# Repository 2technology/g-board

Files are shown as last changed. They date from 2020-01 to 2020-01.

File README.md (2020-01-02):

# G-board V 0.1!
PCB design in order to use a ESP32 DevkitC to drive a relay and 4 seperate WS2812b-channels. It has terminal blocks for easy installation and up to 4 pushbuttons can be connected. It uses a Logic level shifter to communicate with the WS2812b led drivers. **Use case:** Smart lights room controller for Home assistant (ESP32 firmware created with ESPHome).

  - [ESP32 DEVKIT C 32D](https://www.aliexpress.com/item/4000434690235.html)
  - 4 * I2C connection headers
  - 1 * 12V Relay rated 16A ([Schrack RTD34012](https://www.tme.eu/en/details/rtd34012/miniature-electromagnetic-relays/te-connectivity/3-1419108-5/) )
  - 4 * WS2812b LED Output channels (with Logic Level Shifter [74HCT245N](https://www.aliexpress.com/item/4000115614415.html))
  - 4 * debounced pushbutton inputs
  
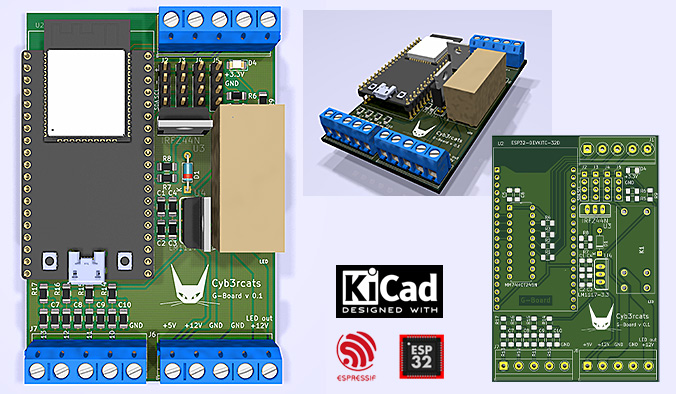
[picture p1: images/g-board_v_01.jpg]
G-Board Version 0.1 G-Board V0.1

  
### Features
#### 12V Relay rated 16A ([Schrack RTD34012](https://www.tme.eu/en/details/rtd34012/miniature-electromagnetic-relays/te-connectivity/3-1419108-5/) )
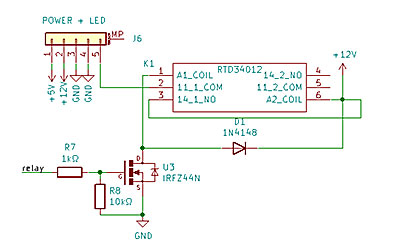
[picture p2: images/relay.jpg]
Relay

#### 4 debounced pushbutton inputs
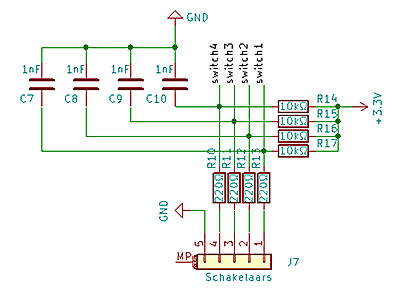
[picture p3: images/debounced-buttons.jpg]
Input-buttons debounced inputs


#### 4 WS2812b LED Output channels (with Logic Level Shifter [74HCT245N](https://www.aliexpress.com/item/4000115614415.html))
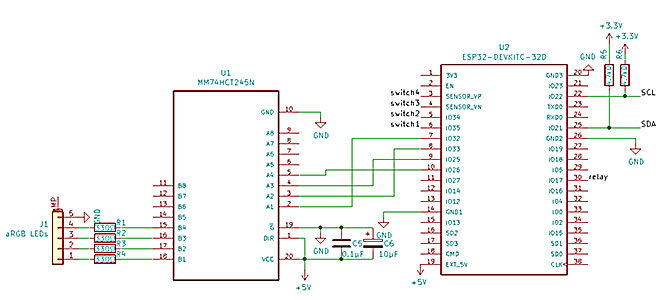
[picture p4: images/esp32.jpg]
Logic-level-shifting esp32


### Schematic and PCB
View [Schematic (pdf)](https://github.com/2technology/g-board/blob/master/G-Board%20V0.1%20-%20Schematic.pdf)

Download KiCAD files: [Schematic](https://github.com/2technology/g-board/blob/master/G-board_V0_1.sch), [PCB](https://github.com/2technology/g-board/blob/master/G-board_V0_1.kicad_pcb)

### Gerbers
Download [Gerbers](https://github.com/2technology/g-board/blob/master/gerbers.zip)
### BOM

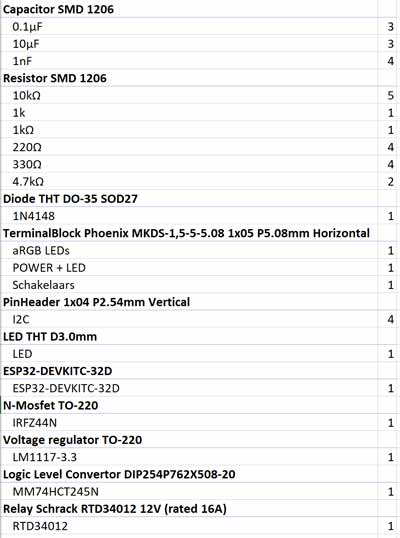
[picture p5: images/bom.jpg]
BOM Version 0.1 BOM G-Board V0.1


### Licence
[GPL-3.0](https://github.com/2technology/g-board/blob/master/LICENSE)

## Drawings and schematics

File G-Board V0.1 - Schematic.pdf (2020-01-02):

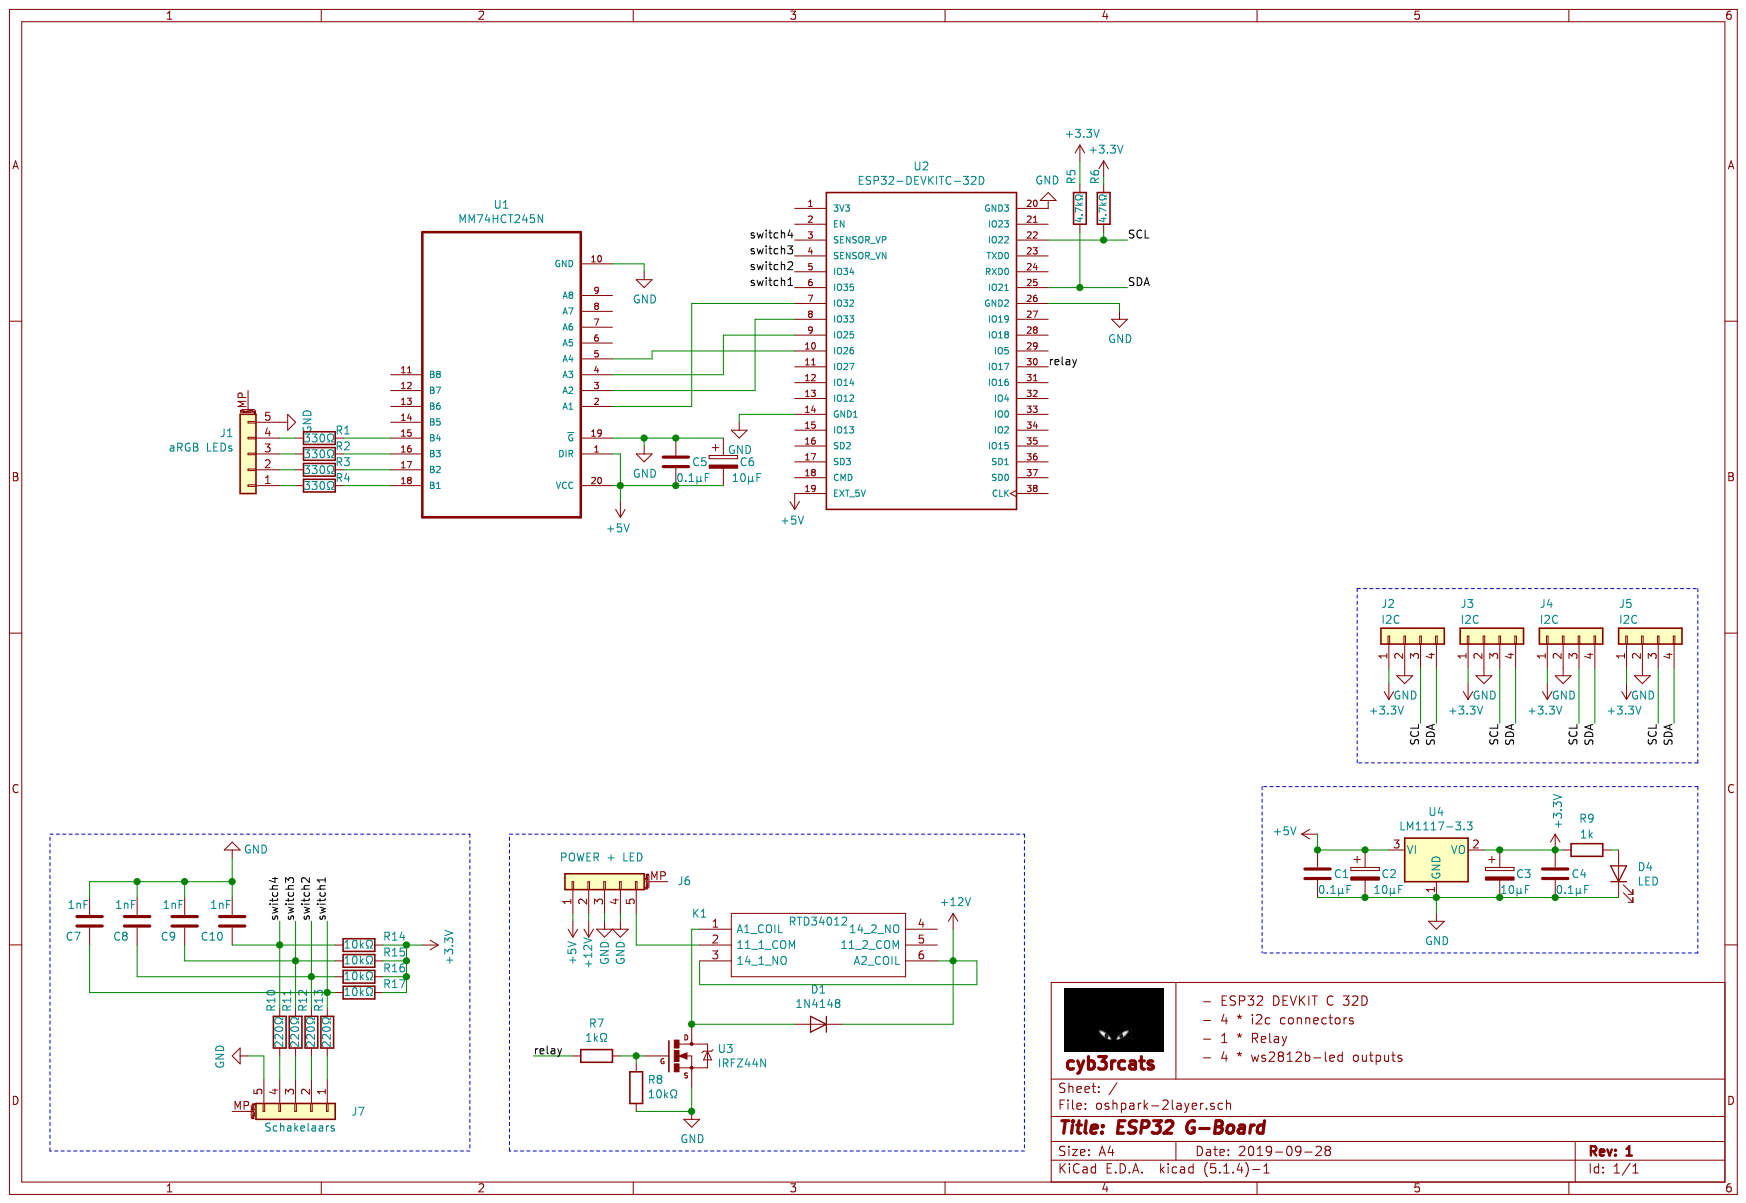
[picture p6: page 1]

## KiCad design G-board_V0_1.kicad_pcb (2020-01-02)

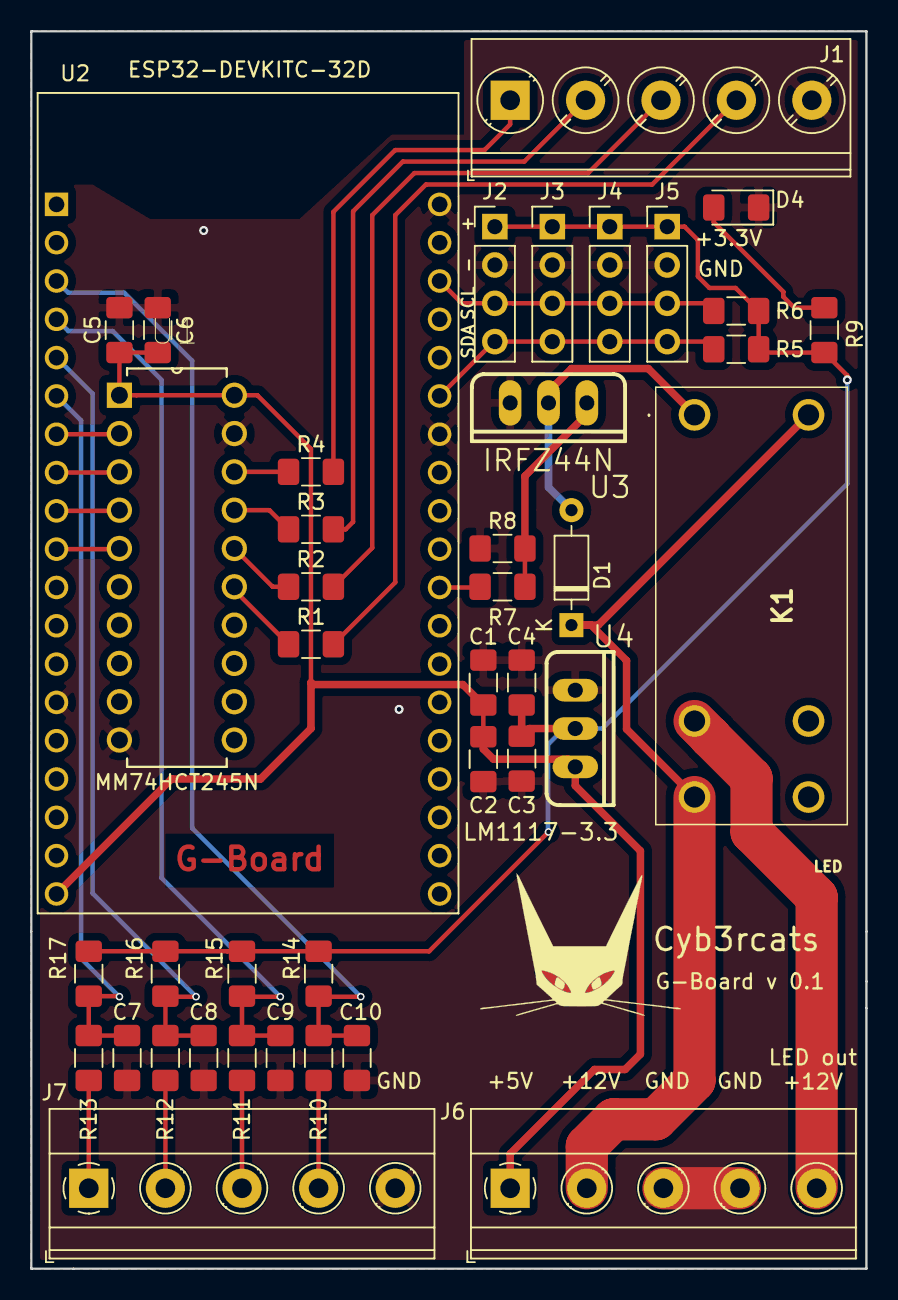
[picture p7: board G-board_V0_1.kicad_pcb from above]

Board: 2 copper layers, 55.4 x 82.0 mm, 42 parts (0 on the bottom side), 31 nets.

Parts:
*: Cyb3rcats; cybercats_logo_silk_cu
C1, C4, C5: 0.1μF; R_1206_3216Metric_Pad1.42x1.75mm_HandSolder
C2, C3, C6: 10μF; R_1206_3216Metric_Pad1.42x1.75mm_HandSolder
C7, C8, C9, C10: 1nF; R_1206_3216Metric_Pad1.42x1.75mm_HandSolder
D1: 1N4148; D_DO-35_SOD27_P7.62mm_Horizontal
D4: LED; LED_1206_3216Metric_Pad1.42x1.75mm_HandSolder
J1: aRGB LEDs; TerminalBlock_Phoenix_PT-1,5-5-5.0-H_1x05_P5.00mm_Horizontal
J2, J3, J4, J5: I2C; PinHeader_1x04_P2.54mm_Vertical
J6: POWER + LED; TerminalBlock_Phoenix_MKDS-1,5-5-5.08_1x05_P5.08mm_Horizont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
J7: Schakelaars; TerminalBlock_Phoenix_MKDS-1,5-5-5.08_1x05_P5.08mm_Horizont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
K1: RTD34012
R1, R2, R3, R4: 330Ω; R_1206_3216Metric_Pad1.42x1.75mm_HandSolder
R5, R6: 4.7kΩ; R_1206_3216Metric_Pad1.42x1.75mm_HandSolder
R7: 1kΩ; R_1206_3216Metric_Pad1.42x1.75mm_HandSolder
R8, R14, R15, R16, R17: 10kΩ; R_1206_3216Metric_Pad1.42x1.75mm_HandSolder
R9: 1k; R_1206_3216Metric_Pad1.42x1.75mm_HandSolder
R10, R11, R12, R13: 220Ω; R_1206_3216Metric_Pad1.42x1.75mm_HandSolder
U1: MM74HCT245N; DIP254P762X508-20
U2: ESP32-DEVKITC-32D; MODULE_ESP32-DEVKITC-32D
U3: IRFZ44N; TO-220
U4: LM1117-3.3; TO-220

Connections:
+3V3: C3.1, C4.1, J2.1, J3.1, J4.1, J5.1, R5.2, R6.2, R9.2, R14.2, R15.2, R16.2, R17.2, U4.2
+5V: C1.1, C2.1, C5.2, C6.2, J6.1, U1.1, U1.20, U2.19, U4.3
+12V: D1.1, J6.2, K1.3, K1.6
/SCL: J2.3, J3.3, J4.3, J5.3, R6.1, U2.22
/SDA: J2.4, J3.4, J4.4, J5.4, R5.1, U2.25
/aRGB1: J1.1, R4.2
/relay: R7.2, U2.30
/switch1: C7.1, R13.2, R17.1, U2.6
/switch2: C8.1, R12.2, R16.1, U2.5
/switch3: C9.1, R11.2, R15.1, U2.4
/switch4: C10.1, R10.2, R14.1, U2.3
GND: C1.2, C2.2, C3.2, C4.2, C5.1, C6.1, C7.2, C8.2, C9.2, C10.2, D4.1, J1.5, J2.2, J3.2, J4.2, J5.2, J6.3, J6.4, J7.5, R8.1, U1.10, U1.19, U2.14, U2.20, U2.26, U3.3, U4.1
unnamed: D1.2, K1.1, U3.2
unnamed: D4.2, R9.1
unnamed: J1.2, R3.2
unnamed: J1.3, R2.2
unnamed: J1.4, R1.2
unnamed: J6.5, K1.2
unnamed: J7.1, R13.1
unnamed: J7.2, R12.1
unnamed: J7.3, R11.1
unnamed: J7.4, R10.1
unnamed: R1.1, U1.15
unnamed: R2.1, U1.16
unnamed: R3.1, U1.17
unnamed: R4.1, U1.18
unnamed: R7.1, R8.2, U3.1
unnamed: U1.2, U2.7
unnamed: U1.3, U2.8
unnamed: U1.4, U2.9
unnamed: U1.5, U2.10
